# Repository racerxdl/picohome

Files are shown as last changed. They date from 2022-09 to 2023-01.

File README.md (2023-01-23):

# PicoHome (WIP)

Raspberry Pi Pico Home Automation using CAN Bus

**PLEASE READ LICENSE WARNING SECTION BEFORE USE**

This project is a improvement over my older home automation projects such as [espshift](https://github.com/racerxdl/esp32-shift). It all started when I wanted to make my own home automation project for learning and I didn't wanted to rely on Wireless Connections for my automation.

This project consists of few parts:

* [picohome-input](/pico-input/README.md) => Board with opto-coupled inputs which works from 12V to 24V switches.
* [picohome-relay](/pico-relay/README.md) => Board that fits on cheap chinese 16 relay board

The main idea is to be able to put everything inside a metal box and forget about it. So far I'm still iterating over designs (I'm running my own home automation for a few years already) and trying to make it less dependent of computers and such.

Work-in-progress = More details to come.

Universal firmware: https://github.com/racerxdl/piho

# LICENSE WARNING

Although all the code and schematics I did here is released under Apache / Creative Commons, the CAN2040 library is released under GPL. The creator of can2040 library doesn't seen to be willing to release it in another license (see https://github.com/KevinOConnor/can2040/issues/5 ) so basically since GPL is more restritive than the one I released, you should follow the GPL for this project.

So how that affects you? It will only affect you if you do distribute a binary version of the firmware. In this case GPL demands you to also release the source code. That's only likely to affect you if you're doing a commercial project and doesn't want to share the source code. Otherwise, you don't need to worry about it.

Although the can2040 library is GPL, everything else here will be as described in LICENSE. If anyone knows or want to do a replacement for can2040 library, let me know :D

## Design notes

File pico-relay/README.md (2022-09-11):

# pico-relay

This board is part of picohome project. It features:

* CAN Bus - Fully controlled through CAN
* 5 bit address - Up to 32 boards in the same CAN bus
* 16 open-collector 200mA outputs that can switch relays up to 24V
* Design to fit over a chinese 16 relay board

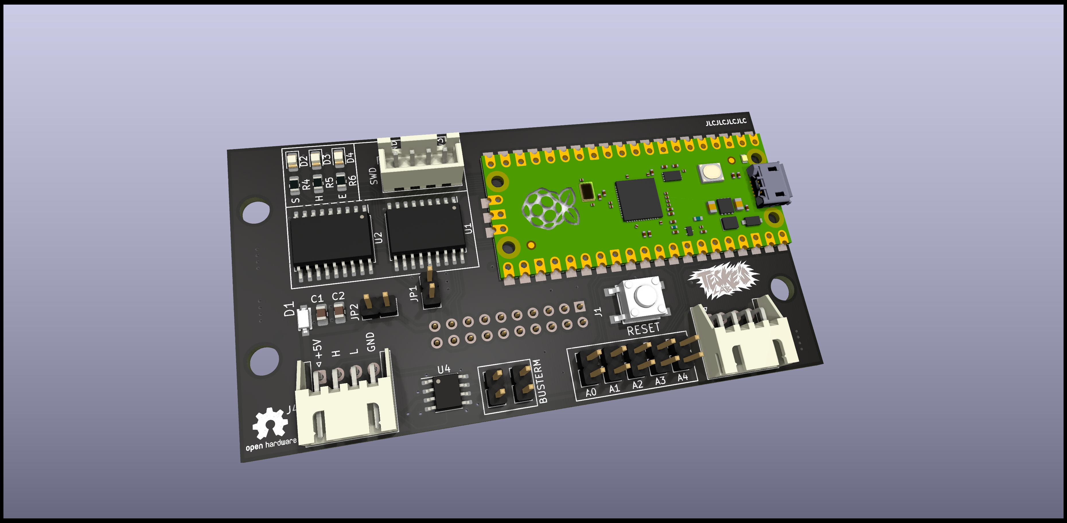
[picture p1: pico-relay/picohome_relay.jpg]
Pico Relay Board


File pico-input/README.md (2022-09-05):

# pico-input

This board is part of picohome project. It features:

* CAN Bus - Fully controlled through CAN
* 5 bit address - Up to 32 boards in the same CAN bus
* 16 opto-coupled inputs which works from 12V to 24V supply directly to momentary touch switches

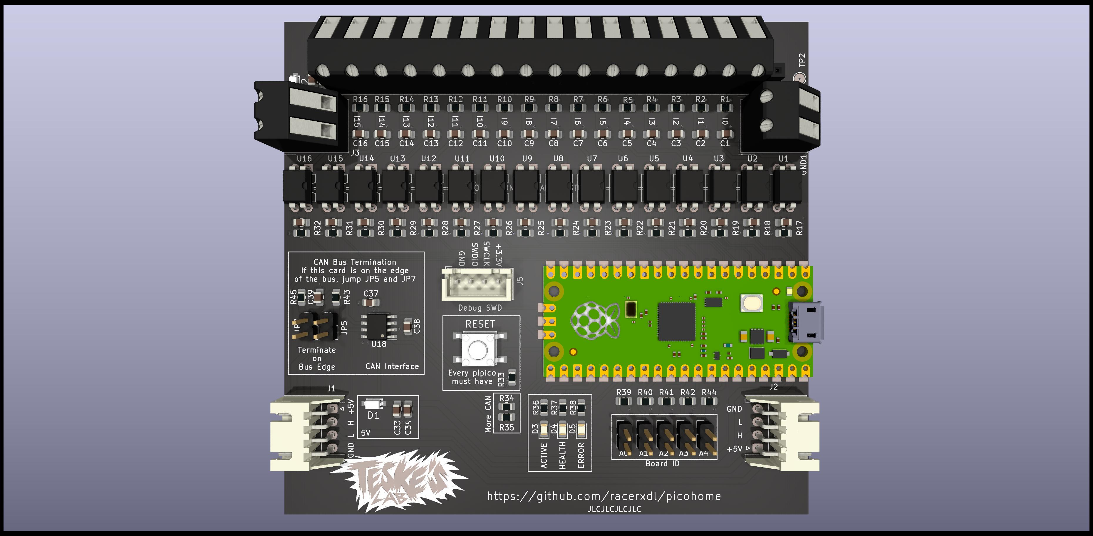
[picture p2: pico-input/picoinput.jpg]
Pico Input Board


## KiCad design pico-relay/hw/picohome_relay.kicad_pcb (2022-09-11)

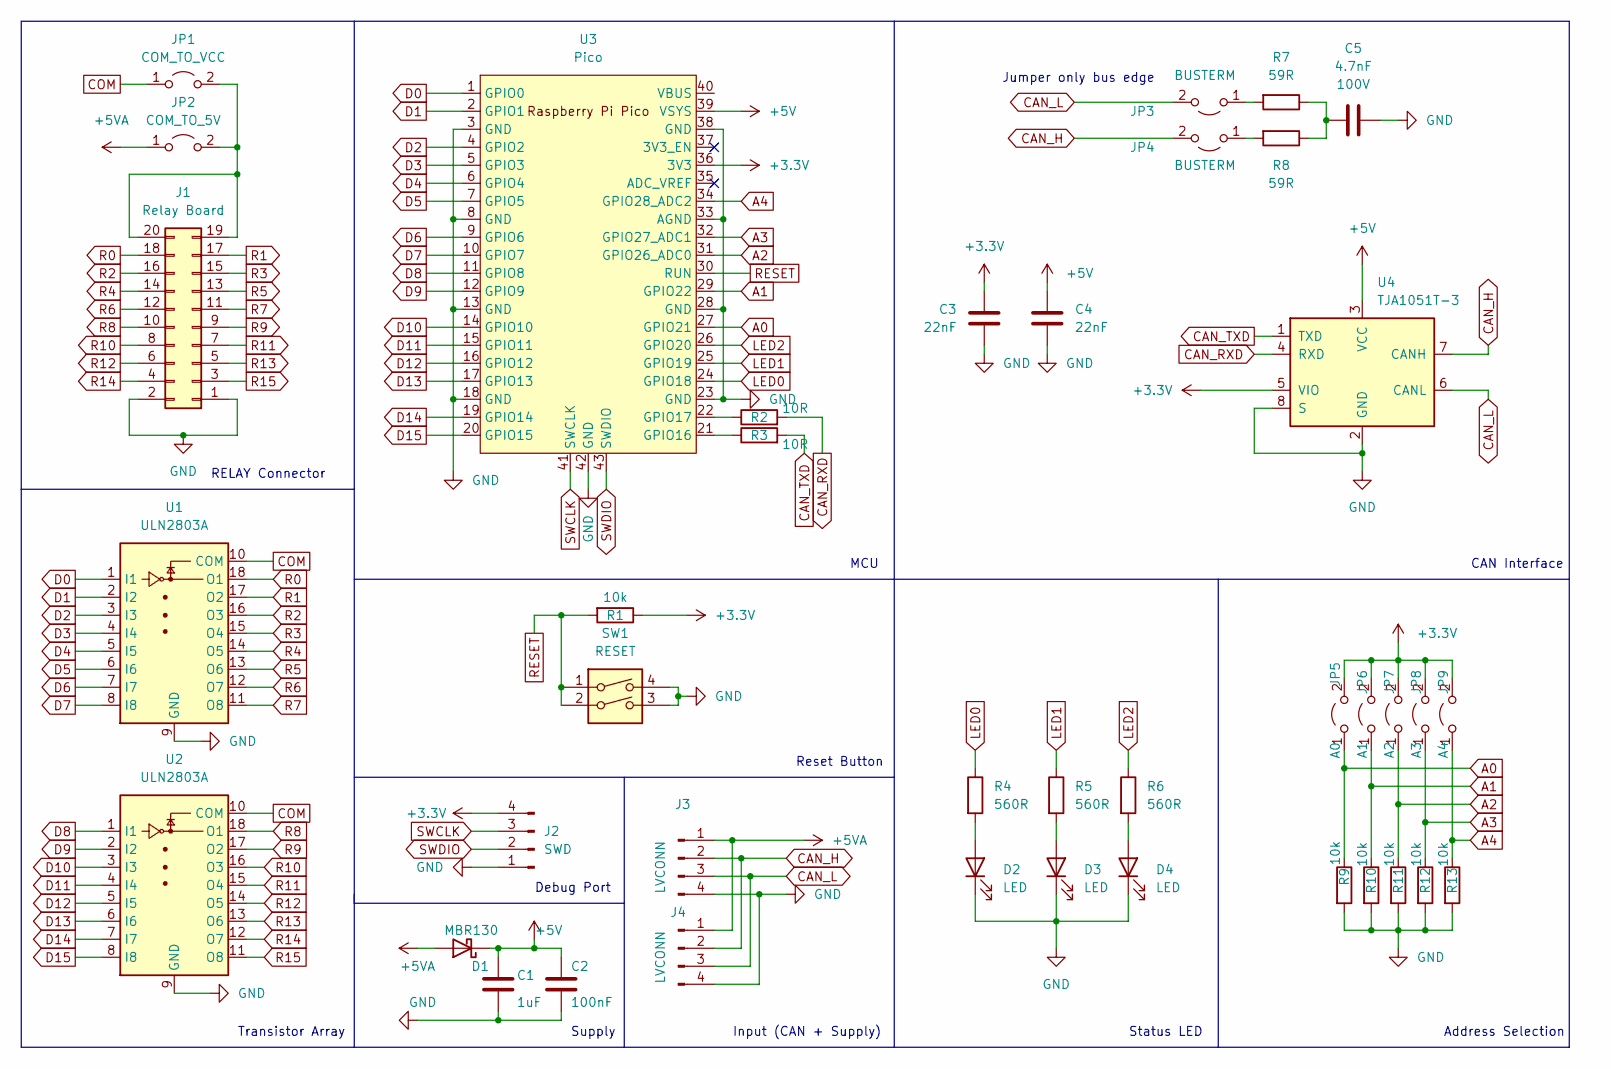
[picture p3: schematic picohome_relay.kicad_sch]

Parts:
C1: 1uF; C_0805_2012Metric_Pad1.18x1.45mm_HandSolder
C2: 100nF; C_0805_2012Metric_Pad1.18x1.45mm_HandSolder
C3, C4: 22nF; C_0805_2012Metric_Pad1.18x1.45mm_HandSolder
C5: 4.7nF; C_0805_2012Metric_Pad1.18x1.45mm_HandSolder; Voltage 100V
D1: MBR130; SOD-123_L2.7-W1.6-LS3.7-RD-1
D2, D3, D4: LED; LED_0805_2012Metric_Pad1.15x1.40mm_HandSolder
J1: Relay Board; PinSocket_2x10_P2.54mm_Vertical
J2: SWD; JST_XH_B4B-XH-A_1x04_P2.50mm_Vertical
J3, J4: LVCONN; JST_XH_S4B-XH-A_1x04_P2.50mm_Horizontal
JP1: COM_TO_VCC; PinHeader_1x02_P2.54mm_Vertical
JP2: COM_TO_5V; PinHeader_1x02_P2.54mm_Vertical
JP3, JP4: BUSTERM; PinHeader_1x02_P2.54mm_Vertical
JP5: A0; PinHeader_1x02_P2.54mm_Vertical
JP6: A1; PinHeader_1x02_P2.54mm_Vertical
JP7: A2; PinHeader_1x02_P2.54mm_Vertical
JP8: A3; PinHeader_1x02_P2.54mm_Vertical
JP9: A4; PinHeader_1x02_P2.54mm_Vertical
R1, R9, R10, R11, R12, R13: 10k; R_0805_2012Metric_Pad1.20x1.40mm_HandSolder
R2, R3: 10R; R_0805_2012Metric_Pad1.20x1.40mm_HandSolder
R4, R5, R6: 560R; R_0805_2012Metric_Pad1.20x1.40mm_HandSolder
R7, R8: 59R; R_0805_2012Metric_Pad1.20x1.40mm_HandSolder
SW1: RESET; SW-SMD_4P-L6.2-W6.2-P4.50-LS9.0
U1, U2: ULN2803A; SOIC-18W_7.5x11.6mm_P1.27mm
U3: Pico; RPi_Pico_SMD_TH
U4: TJA1051T-3; SOIC-8_3.9x4.9mm_P1.27mm

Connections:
+3V3: C3.1, J2.4, JP5.2 (B), JP6.2 (B), JP7.2 (B), JP8.2 (B), JP9.2 (B), R1.1, U3.36 (3V3), U4.5 (VIO)
+5V: C1.1, C2.1, C4.1, D1.1 (K), U3.39 (VSYS), U4.3 (VCC)
+5VA: D1.2 (A), J3.1, J4.1, JP2.1 (A)
A0: JP5.1 (A), R9.1, U3.27 (GPIO21)
A1: JP6.1 (A), R10.1, U3.29 (GPIO22)
A2: JP7.1 (A), R11.1, U3.31 (GPIO26_ADC0)
A3: JP8.1 (A), R12.1, U3.32 (GPIO27_ADC1)
A4: JP9.1 (A), R13.1, U3.34 (GPIO28_ADC2)
CAN_H: J3.2, J4.2, JP4.2 (B), U4.7 (CANH)
CAN_L: J3.3, J4.3, JP3.2 (B), U4.6 (CANL)
CAN_RXD: R2.2, U4.4 (RXD)
CAN_TXD: R3.2, U4.1 (TXD)
COM: JP1.1 (A), U1.10 (COM), U2.10 (COM)
D0: U1.1 (I1), U3.1 (GPIO0)
D1: U1.2 (I2), U3.2 (GPIO1)
D2: U1.3 (I3), U3.4 (GPIO2)
D3: U1.4 (I4), U3.5 (GPIO3)
D4: U1.5 (I5), U3.6 (GPIO4)
D5: U1.6 (I6), U3.7 (GPIO5)
D6: U1.7 (I7), U3.9 (GPIO6)
D7: U1.8 (I8), U3.10 (GPIO7)
D8: U2.1 (I1), U3.11 (GPIO8)
D9: U2.2 (I2), U3.12 (GPIO9)
D10: U2.3 (I3), U3.14 (GPIO10)
D11: U2.4 (I4), U3.15 (GPIO11)
D12: U2.5 (I5), U3.16 (GPIO12)
D13: U2.6 (I6), U3.17 (GPIO13)
D14: U2.7 (I7), U3.19 (GPIO14)
D15: U2.8 (I8), U3.20 (GPIO15)
GND: C1.2, C2.2, C3.2, C4.2, C5.2, D2.1 (K), D3.1 (K), D4.1 (K), J1.1, J1.2, J2.1, J3.4, J4.4, R9.2, R10.2, R11.2, R12.2, R13.2, SW1.3, SW1.4, U1.9 (GND), U2.9 (GND), U3.3 (GND), U3.8 (GND), U3.13 (GND), U3.18 (GND), U3.23 (GND), U3.28 (GND), U3.33 (AGND), U3.38 (GND), U3.42 (GND), U4.2 (GND), U4.8 (S)
LED0: R4.1, U3.24 (GPIO18)
LED1: R5.1, U3.25 (GPIO19)
LED2: R6.1, U3.26 (GPIO20)
unnamed: C5.1, R7.1, R8.1
unnamed: D2.2 (A), R4.2
unnamed: D3.2 (A), R5.2
unnamed: D4.2 (A), R6.2
unnamed: J1.19, J1.20, JP1.2 (B), JP2.2 (B)
unnamed: JP3.1 (A), R7.2
unnamed: JP4.1 (A), R8.2
unnamed: R2.1, U3.22 (GPIO17)
unnamed: R3.1, U3.21 (GPIO16)
R0: J1.18, U1.18 (O1)
R1: J1.17, U1.17 (O2)
R2: J1.16, U1.16 (O3)
R3: J1.15, U1.15 (O4)
R4: J1.14, U1.14 (O5)
R5: J1.13, U1.13 (O6)
R6: J1.12, U1.12 (O7)
R7: J1.11, U1.11 (O8)
R8: J1.10, U2.18 (O1)
R9: J1.9, U2.17 (O2)
R10: J1.8, U2.16 (O3)
R11: J1.7, U2.15 (O4)
R12: J1.6, U2.14 (O5)
R13: J1.5, U2.13 (O6)
R14: J1.4, U2.12 (O7)
R15: J1.3, U2.11 (O8)
RESET: R1.2, SW1.1, SW1.2, U3.30 (RUN)
SWCLK: J2.3, U3.41 (SWCLK)
SWDIO: J2.2, U3.43 (SWDIO)

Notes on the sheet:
CAN Interface
Address Selection
Transistor Array
Debug Port
MCU
RELAY Connector
Jumper only bus edge
Status LED
Reset Button
Supply
Input (CAN + Supply)

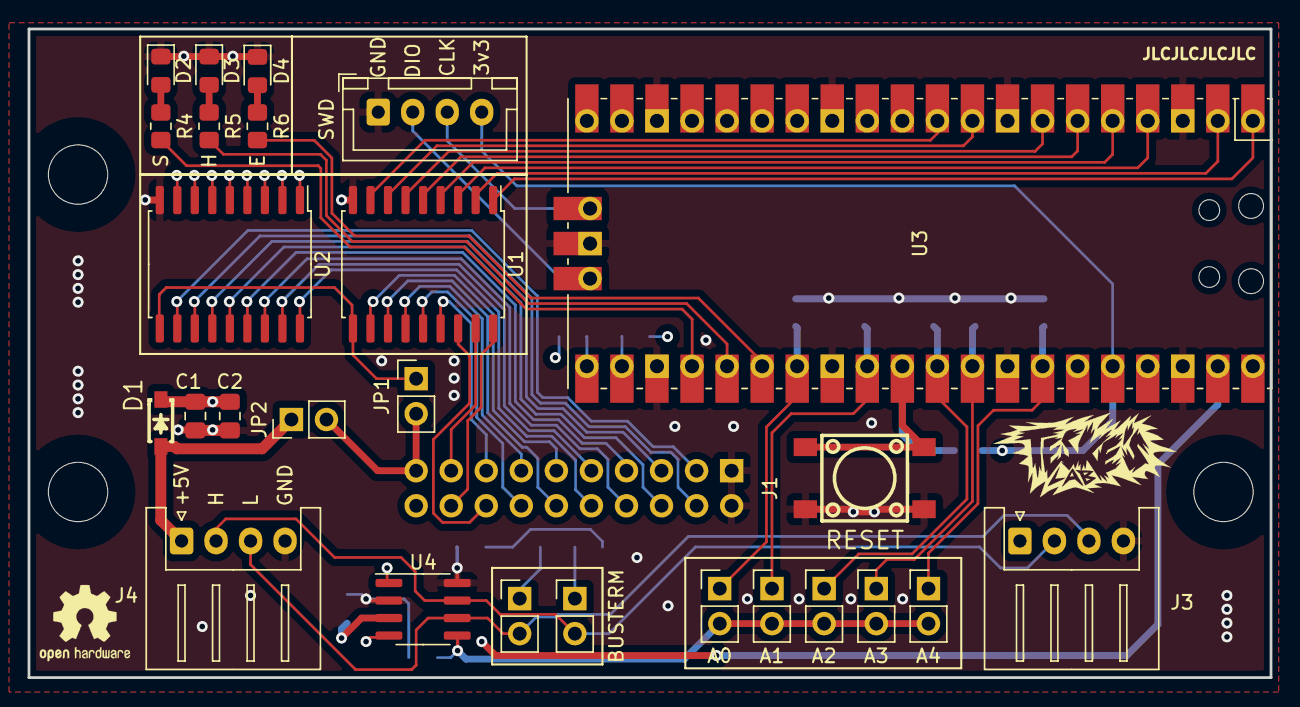
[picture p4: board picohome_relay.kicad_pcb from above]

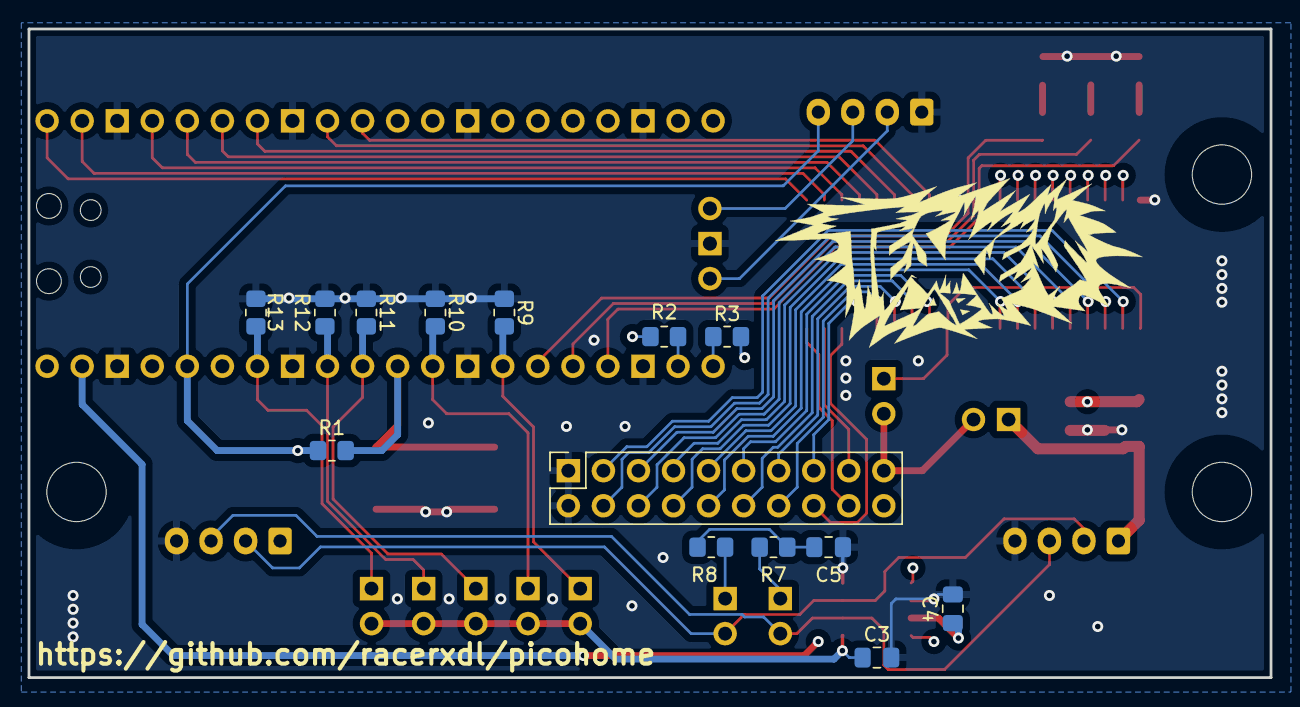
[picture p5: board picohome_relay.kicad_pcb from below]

Board: 4 copper layers, 90.0 x 47.0 mm, 40 parts (14 on the bottom side), 61 nets.

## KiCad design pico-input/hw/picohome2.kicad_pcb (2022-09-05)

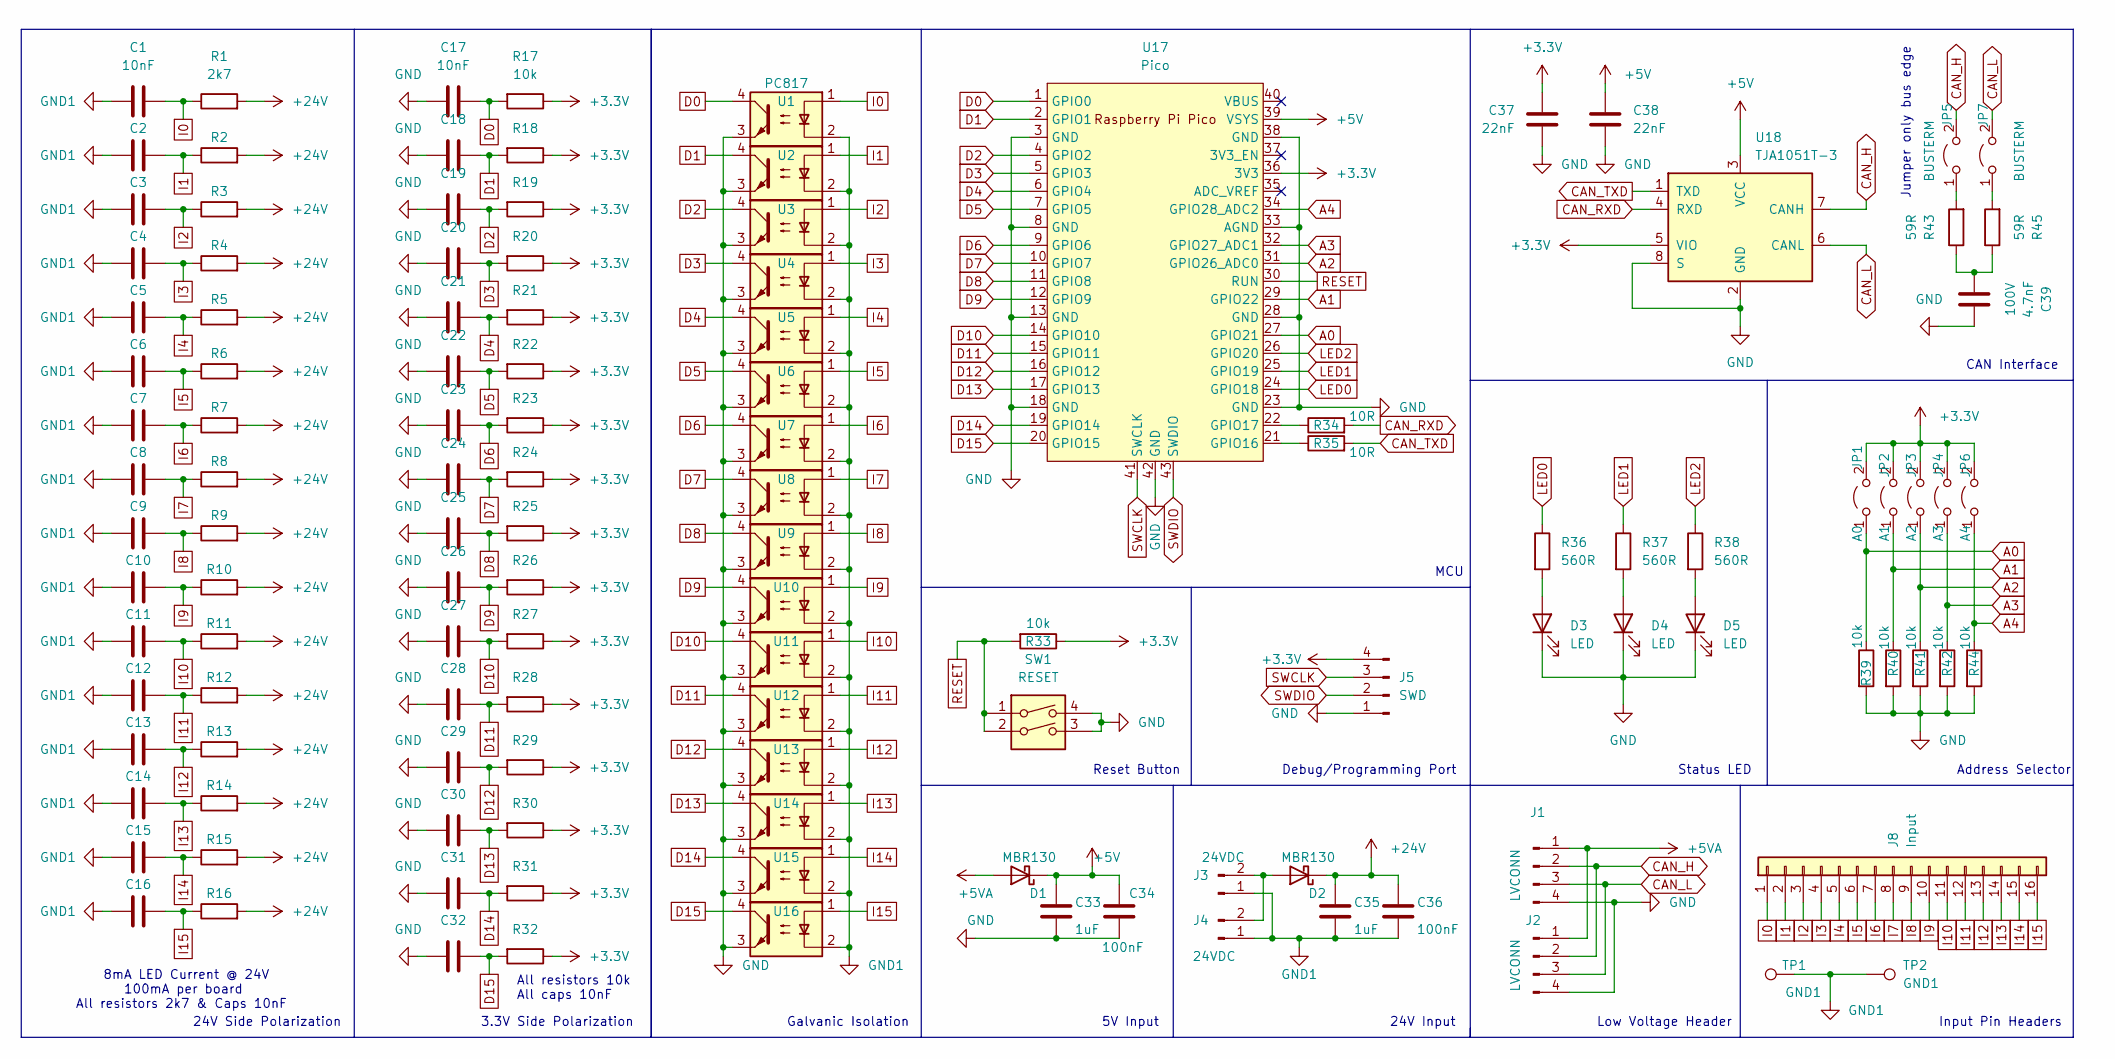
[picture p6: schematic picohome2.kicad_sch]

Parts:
C1, C2, C3, C4, C5, C6, C7, C8, C9, C10, C11, C12, C13, C14, C15, C16, C17, C18, C19, C20, C21, C22, C23, C24, C25, C26, C27, C28, C29, C30, C31, C32: 10nF; C_0805_2012Metric_Pad1.18x1.45mm_HandSolder
C33, C35: 1uF; C_0805_2012Metric_Pad1.18x1.45mm_HandSolder
C34, C36: 100nF; C_0805_2012Metric_Pad1.18x1.45mm_HandSolder
C37, C38: 22nF; C_0805_2012Metric_Pad1.18x1.45mm_HandSolder
C39: 4.7nF; C_0805_2012Metric_Pad1.18x1.45mm_HandSolder; Voltage 100V
D1, D2: MBR130; SOD-123_L2.7-W1.6-LS3.7-RD-1
D3, D4, D5: LED; LED_0805_2012Metric_Pad1.15x1.40mm_HandSolder
J1, J2: LVCONN; JST_XH_S4B-XH-A_1x04_P2.50mm_Horizontal
J3, J4: 24VDC; Altech_AK300_1x02_P5.00mm_45-Degree
J5: SWD; JST_XH_B4B-XH-A_1x04_P2.50mm_Vertical
J8: Input; Altech_AK300_1x16_P5.00mm_45-Degree
JP1: A0; PinHeader_1x02_P2.54mm_Vertical
JP2: A1; PinHeader_1x02_P2.54mm_Vertical
JP3: A2; PinHeader_1x02_P2.54mm_Vertical
JP4: A3; PinHeader_1x02_P2.54mm_Vertical
JP5, JP7: BUSTERM; PinHeader_1x02_P2.54mm_Vertical
JP6: A4; PinHeader_1x02_P2.54mm_Vertical
R1, R2, R3, R4, R5, R6, R7, R8, R9, R10, R11, R12, R13, R14, R15, R16: 2k7; R_0805_2012Metric_Pad1.20x1.40mm_HandSolder
R17, R18, R19, R20, R21, R22, R23, R24, R25, R26, R27, R28, R29, R30, R31, R32, R33, R39, R40, R41, R42, R44: 10k; R_0805_2012Metric_Pad1.20x1.40mm_HandSolder
R34, R35: 10R; R_0805_2012Metric_Pad1.20x1.40mm_HandSolder
R36, R37, R38: 560R; R_0805_2012Metric_Pad1.20x1.40mm_HandSolder
R43, R45: 59R; R_0805_2012Metric_Pad1.20x1.40mm_HandSolder
SW1: RESET; SW-SMD_4P-L6.2-W6.2-P4.50-LS9.0
TP1: GND1; PinSocket_1x01_P2.54mm_Vertical
TP2: GND1; TestPoint_Pad_D2.0mm
U1, U2, U3, U4, U5, U6, U7, U8, U9, U10, U11, U12, U13, U14, U15, U16: PC817; DIP-4_W7.62mm
U17: Pico; RPi_Pico_SMD_TH
U18: TJA1051T-3; SOIC-8_3.9x4.9mm_P1.27mm

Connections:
+3V3: C37.1, J5.4, JP1.2 (B), JP2.2 (B), JP3.2 (B), JP4.2 (B), JP6.2 (B), R17.1, R18.1, R19.1, R20.1, R21.1, R22.1, R23.1, R24.1, R25.1, R26.1, R27.1, R28.1, R29.1, R30.1, R31.1, R32.1, R33.1, U17.36 (3V3), U18.5 (VIO)
+5V: C33.1, C34.1, C38.1, D1.1 (K), U17.39 (VSYS), U18.3 (VCC)
+5VA: D1.2 (A), J1.1, J2.1
+24V: C35.1, C36.1, D2.1 (K), R1.2, R2.2, R3.2, R4.2, R5.2, R6.2, R7.2, R8.2, R9.2, R10.2, R11.2, R12.2, R13.2, R14.2, R15.2, R16.2
A0: JP1.1 (A), R39.1, U17.27 (GPIO21)
A1: JP2.1 (A), R40.1, U17.29 (GPIO22)
A2: JP3.1 (A), R41.1, U17.31 (GPIO26_ADC0)
A3: JP4.1 (A), R42.1, U17.32 (GPIO27_ADC1)
A4: JP6.1 (A), R44.1, U17.34 (GPIO28_ADC2)
CAN_H: J1.2, J2.2, JP5.2 (B), U18.7 (CANH)
CAN_L: J1.3, J2.3, JP7.2 (B), U18.6 (CANL)
CAN_RXD: R34.2, U18.4 (RXD)
CAN_TXD: R35.2, U18.1 (TXD)
D0: C17.2, R17.2, U1.4, U17.1 (GPIO0)
D1: C18.2, R18.2, U2.4, U17.2 (GPIO1)
D2: C19.2, R19.2, U3.4, U17.4 (GPIO2)
D3: C20.2, R20.2, U4.4, U17.5 (GPIO3)
D4: C21.2, R21.2, U5.4, U17.6 (GPIO4)
D5: C22.2, R22.2, U6.4, U17.7 (GPIO5)
D6: C23.2, R23.2, U7.4, U17.9 (GPIO6)
D7: C24.2, R24.2, U8.4, U17.10 (GPIO7)
D8: C25.2, R25.2, U9.4, U17.11 (GPIO8)
D9: C26.2, R26.2, U10.4, U17.12 (GPIO9)
D10: C27.2, R27.2, U11.4, U17.14 (GPIO10)
D11: C28.2, R28.2, U12.4, U17.15 (GPIO11)
D12: C29.2, R29.2, U13.4, U17.16 (GPIO12)
D13: C30.2, R30.2, U14.4, U17.17 (GPIO13)
D14: C31.2, R31.2, U15.4, U17.19 (GPIO14)
D15: C32.2, R32.2, U16.4, U17.20 (GPIO15)
GND: C17.1, C18.1, C19.1, C20.1, C21.1, C22.1, C23.1, C24.1, C25.1, C26.1, C27.1, C28.1, C29.1, C30.1, C31.1, C32.1, C33.2, C34.2, C37.2, C38.2, C39.2, D3.1 (K), D4.1 (K), D5.1 (K), J1.4, J2.4, J5.1, R39.2, R40.2, R41.2, R42.2, R44.2, SW1.3, SW1.4, U1.3, U2.3, U3.3, U4.3, U5.3, U6.3, U7.3, U8.3, U9.3, U10.3, U11.3, U12.3, U13.3, U14.3, U15.3, U16.3, U17.3 (GND), U17.8 (GND), U17.13 (GND), U17.18 (GND), U17.23 (GND), U17.28 (GND), U17.33 (AGND), U17.38 (GND), U17.42 (GND), U18.2 (GND), U18.8 (S)
GND1: C1.1, C2.1, C3.1, C4.1, C5.1, C6.1, C7.1, C8.1, C9.1, C10.1, C11.1, C12.1, C13.1, C14.1, C15.1, C16.1, C35.2, C36.2, J3.1, J4.1, TP1.1, TP2.1, U1.2, U2.2, U3.2, U4.2, U5.2, U6.2, U7.2, U8.2, U9.2, U10.2, U11.2, U12.2, U13.2, U14.2, U15.2, U16.2
I0: C1.2, J8.1, R1.1, U1.1
I1: C2.2, J8.2, R2.1, U2.1
I2: C3.2, J8.3, R3.1, U3.1
I3: C4.2, J8.4, R4.1, U4.1
I4: C5.2, J8.5, R5.1, U5.1
I5: C6.2, J8.6, R6.1, U6.1
I6: C7.2, J8.7, R7.1, U7.1
I7: C8.2, J8.8, R8.1, U8.1
I8: C9.2, J8.9, R9.1, U9.1
I9: C10.2, J8.10, R10.1, U10.1
I10: C11.2, J8.11, R11.1, U11.1
I11: C12.2, J8.12, R12.1, U12.1
I12: C13.2, J8.13, R13.1, U13.1
I13: C14.2, J8.14, R14.1, U14.1
I14: C15.2, J8.15, R15.1, U15.1
I15: C16.2, J8.16, R16.1, U16.1
LED0: R36.1, U17.24 (GPIO18)
LED1: R37.1, U17.25 (GPIO19)
LED2: R38.1, U17.26 (GPIO20)
unnamed: C39.1, R43.1, R45.1
unnamed: D2.2 (A), J3.2, J4.2
unnamed: D3.2 (A), R36.2
unnamed: D4.2 (A), R37.2
unnamed: D5.2 (A), R38.2
unnamed: JP5.1 (A), R43.2
unnamed: JP7.1 (A), R45.2
unnamed: R34.1, U17.22 (GPIO17)
unnamed: R35.1, U17.21 (GPIO16)
RESET: R33.2, SW1.1, SW1.2, U17.30 (RUN)
SWCLK: J5.3, U17.41 (SWCLK)
SWDIO: J5.2, U17.43 (SWDIO)

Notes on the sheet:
8mA LED Current @ 24V 100mA per board All resistors 2k7 & Caps 10nF
Galvanic Isolation
5V Input
Low Voltage Header
Jumper only bus edge
Debug/Programming Port
Input Pin Headers
CAN Interface
3.3V Side Polarization
Reset Button
MCU
Address Selector
All resistors 10k All caps 10nF
24V Input
24V Side Polarization
Status LED

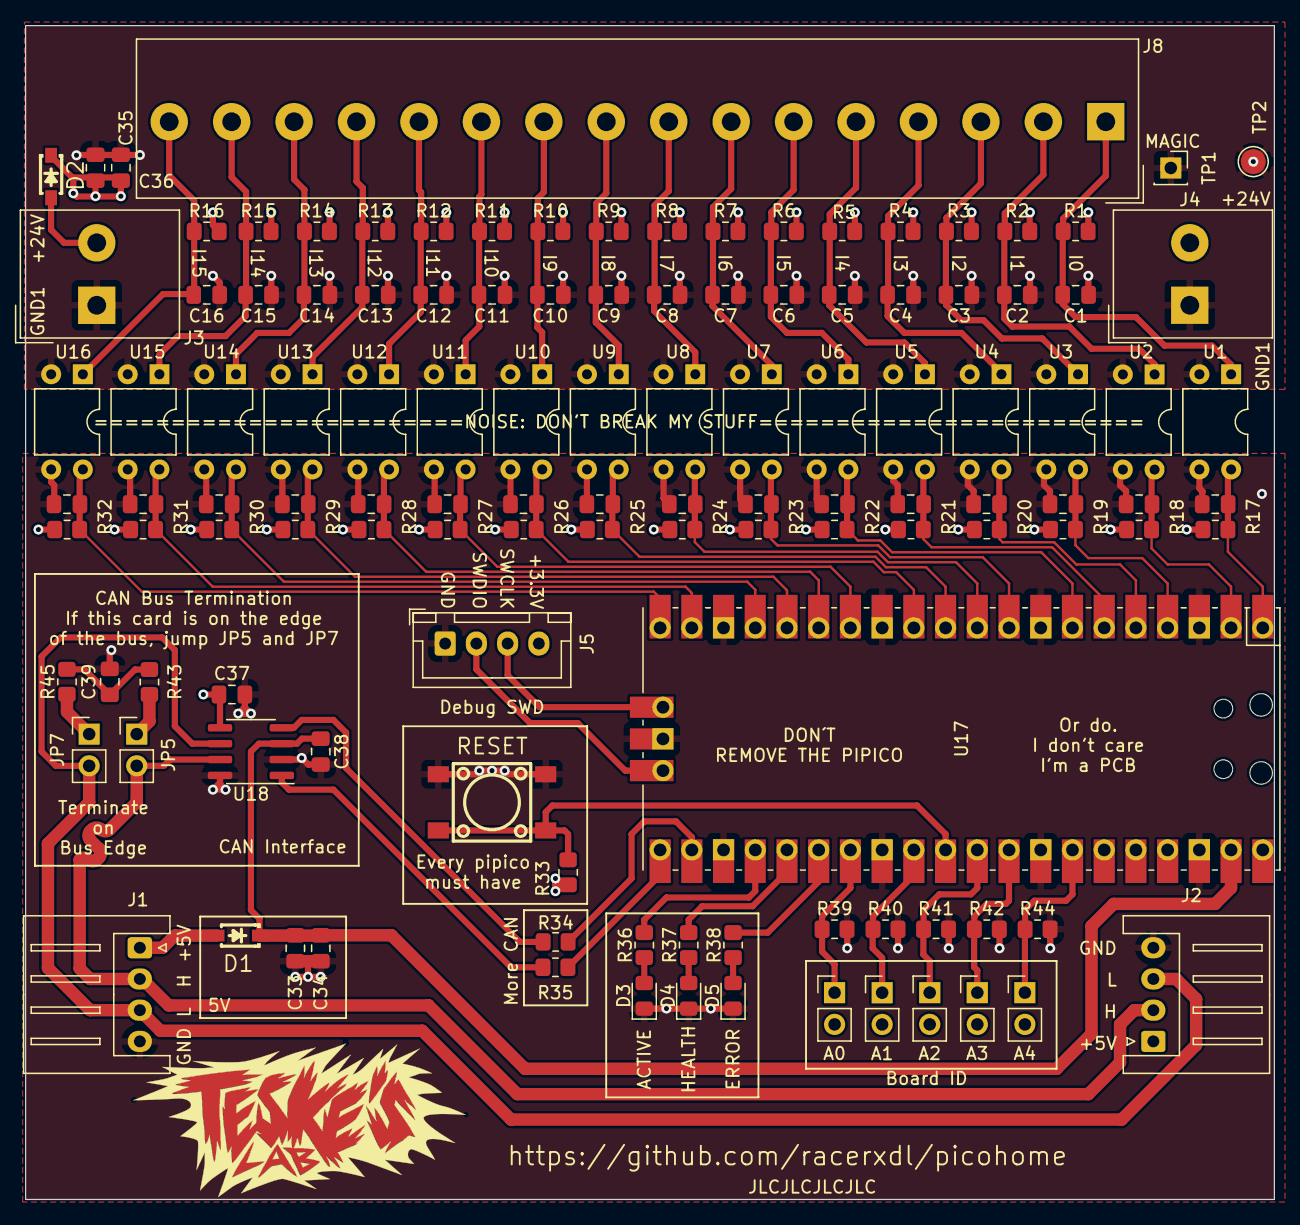
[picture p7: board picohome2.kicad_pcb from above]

Board: 4 copper layers, 100.0 x 94.0 mm, 123 parts (0 on the bottom side), 62 nets.

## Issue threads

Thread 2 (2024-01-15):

16 channel board?

samuk, 2024-01-15:
This looks interesting. I'm unclear which 'chinese 16 channel relay' you mean? Could you provide a link please?

Presumably, the software side would work with [Adafruit Canbus Picobell](https://learn.adafruit.com/adafruit-picowbell-can-bus-for-pico) and this [relay board](https://easyeda.com/editor#id=1d55922e6ea745ebb05257c89cfed4da)?

racerxdl, 2024-01-15:
Its the generic ones like this https://s.click.aliexpress.com/e/_Dku5fFF
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

samuk, 2024-01-15:
OK thanks. I still don't quite get how the two are connected. 16 channel is overkill for me anyway.

Would you anticipate any issues running your firmware on
[Feather relay](https://www.adafruit.com/product/3191)
[Feather Canbus/ Pico](https://www.adafruit.com/product/5724)

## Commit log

2022-09-05 Add pico-input alfa
    [picohome2.kicad_pcb, picohome2.kicad_sch]
2022-09-05 Add pico-input README
2022-09-11 Add picohome relay board
    [picohome_relay.kicad_pcb, picohome_relay.kicad_sch]
2022-10-16 Updated input control to real board.
2023-01-23 Update 24V Pull-up resistors to 10k (2k7 dissipates too much heat)
    [picohome2.kicad_sch]
